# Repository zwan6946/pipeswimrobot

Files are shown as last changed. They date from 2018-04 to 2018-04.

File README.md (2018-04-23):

# pipeswimrobot

#function of the robot:Every day, pipeline leakage causes a large amount of water (or oil, gas,etc.) lost. The old way to detect the pipeline leakage always consume a lot of times and human resources. It is in need to have an new leakage detection	way to offer help. SwimBot is designed for low-cost, constantly-running leakage detection.
#
#Design:

location detecting:
Using the IMU built in the Arduino 101 board, which include 3-axis gyroscope and 3-axis accelerometer, to detect the position.
Writing data as a format of the number, time, microphone, 3-axis gyroscope and 3-axis accelerometer into sd card.
Using outside Matlab function to analyzing the data we load in SD card to get the position of leaking. and also use machine learning to simulate the size of leaking

Microphone 
Maxim MAX4466 is an op-amp specifically designed for a delicate task which can recorded 20-20KHZ electret sounds. This microphone is very suitable for detecting varieties size of leaking. 

M100 Brushless Motor with propeller ($82.00)
This motor is a rugged brushless motor for use in the ocean and in extreme environments. This propeller with M100 motor can generates about 3.2 lb of forward thrust and 2.6 ln of  reverse thrust.

Speed controller 
This controller is based on the BLHeli_S ESC design, providing an speed control and voltage adjustment for Motors.

Outfit
Using 3D printer to print a special outer casing or shell for this swimming robot. The whole device is designed like a bullet so it can reduce the force of water. There is a gap surrounding the chips so it can isolate water from chips

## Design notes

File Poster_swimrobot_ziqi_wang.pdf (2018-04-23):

# Developing swimming in pipe robot

## Student: Ziqi Wang, Electrical Engineering (computer), University of Sydney

Director: Dr. Stevan Dubljevic, Department of Chemical and Material Engineering, University of Alberta

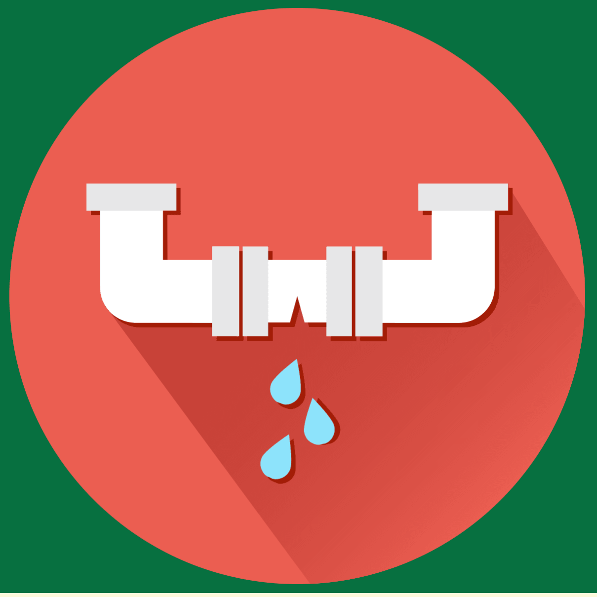
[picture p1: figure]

## Introduction

Every day, pipeline leakage causes a large amount of water (or oil, gas,etc.) lost. The old way to detect the pipeline leakage always consume a lot of times and human resources.
It is in need to have an new leakage detection way to offer help. SwimBot is designed for low-cost, constantly-running leakage detection.

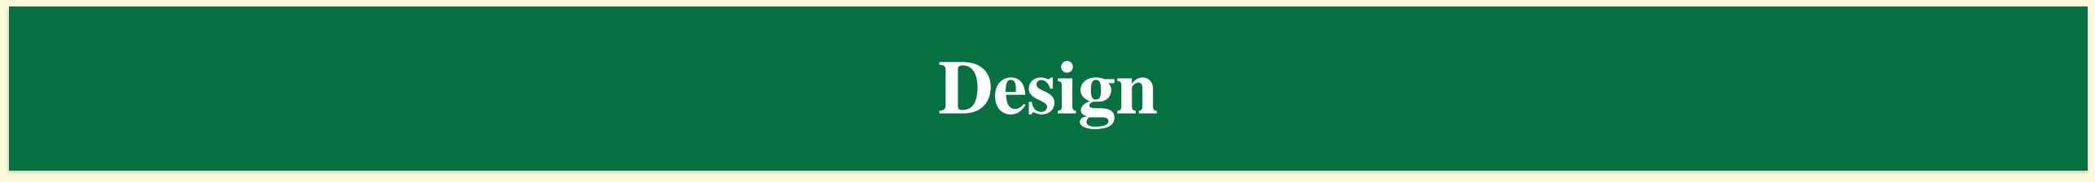
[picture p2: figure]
Design

Hardware
Arduino 101 microcontroller ($30.00)
This board has low power consumption of inter curie module with an IMU and a Bluetooth unit inside. There are 14 output/input pins on this board, which can provide enough interface for this project.

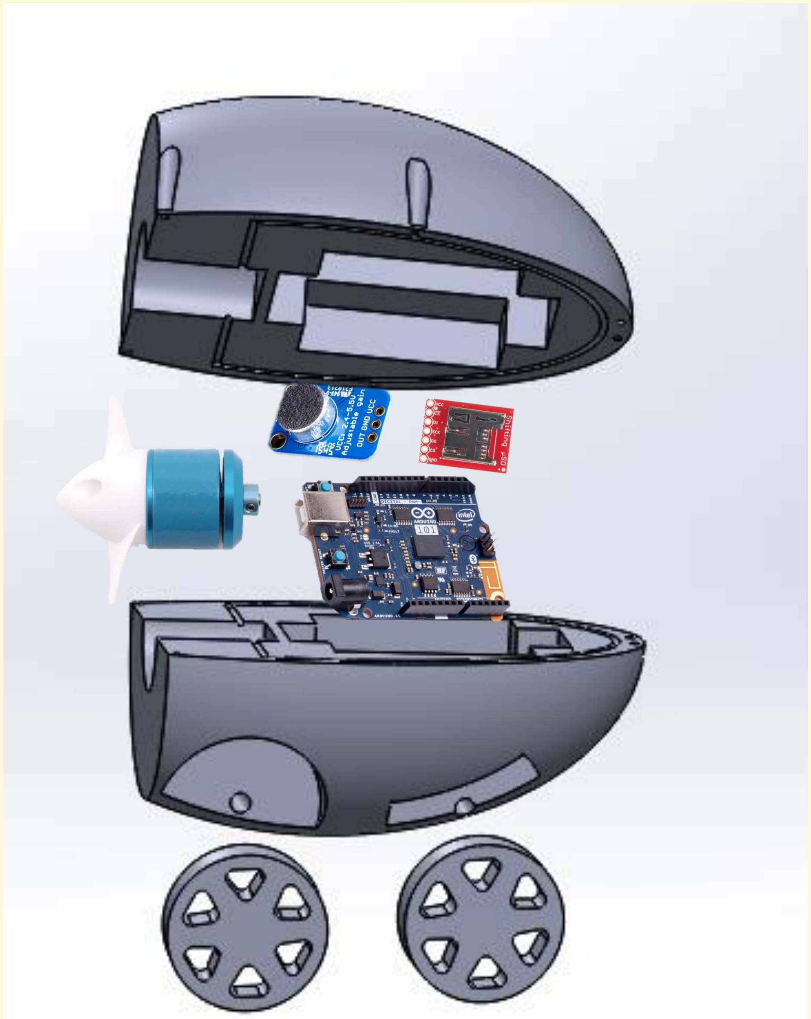
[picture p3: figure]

Microphone ($6.49)
Maxim MAX4466 is an op-amp specifically designed for a delicate task which can recorded 20-20KHZ electret sounds. This microphone is very suitable for detecting varieties size of leaking.

MicroSD Shied ($4.95)
Using MicroSD card to minimize the size of the core part and also use it to load IMU data and Microphone data.

M100 Brushless Motor with propeller ($82.00) This motor is a rugged brushless motor for use in the ocean and in extreme environments. This propeller with M100 motor can generates about 3.2 lb of forward thrust and 2.6 ln of reverse thrust.

Speed controller ($25.00)
This controller is based on the BLHeli_S ESC design, providing an speed control and voltage adjustment for Motors.

Outfit
Using 3D printer to print a special outer casing or shell for this swimming robot. The whole device is designed like a bullet so it can reduce the force of water. There is a gap surrounding the chips so it can isolate water from chips.

Software
IMU
IMU (Inertial measurement unit) is an electronic device that measures and reports a body‘s specific force and angular rate, using a combination of accelerometer and gyroscope.

Big Data Analysis
To detect the leak with sound data, we should find ways to tell apart the difference between normal sound signals and the ones at leak points.
Once we get the raw data of the sound from the microphone, we should first identify the feature vector of the sound. Then, we use machine learning methods to classify leak and non-leak situations.

## Methods

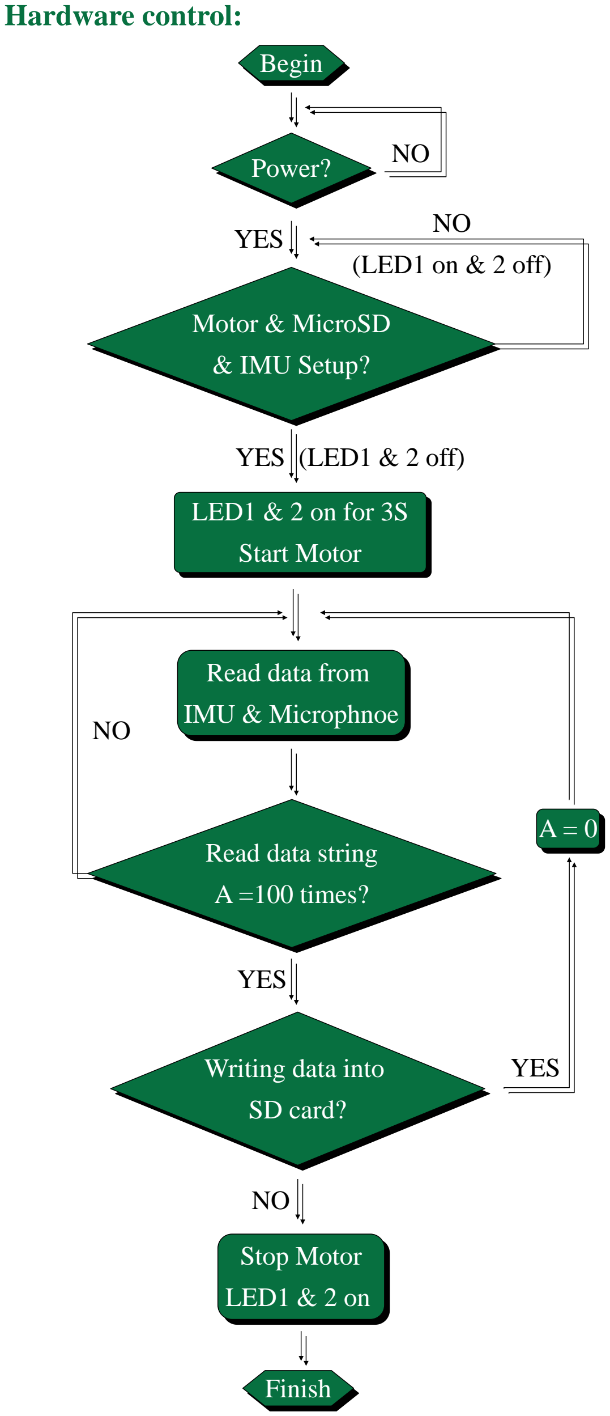
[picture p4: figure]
Hardware control:; Power?; Begin; YES; Motor & MicroSD; & IMU Setup?; (LED1 on & 2 off); YES (LED1 & 2 off); LED1 & 2 on for 3S; Start Motor; Read data string; A =100 times?; Read data from; IMU & Microphnoe NO; Writing data into; SD card?; Stop Motor; LED1 & 2 on; Finish

Position Detection

Using the IMU built in the Arduino 101 board, which include 3-axis gyroscope and 3-axis accelerometer, to detect the position.
Writing data as a format of the number, time, microphone, 3-axis gyroscope and 3-axis accelerometer into sd card. Using outside Matlab function to analyzing the data we load in SD card to get the position of leaking. and also use machine learning to simulate the size of leaking

3D model of swimrobot

## Conclusions

Power consumption

The motor consumes a lot of energies, a 600mAh battery can only support for 30 minis as the motor is running at a maximum speed.

Motor

This type of motor is perfect for small devices which require going deep into the water. This motor also provides adjustable forward and backward thrust. This force can be used to break the clogging pipes.

Data processing

There is some conflict between IO interfaces, which causes the unstable of data collection. The time used in writing data into SD card when getting 100 groups of data, may cause lost one or two groups of data. However, the influence to the position detection can be eliminated.

## Further Study

- Try to using FPGA to building an stable version of swimming robot, Which will reduce the conflict between IO ports.
- Using machine learning to calculate the position of the swimming robot, like to calculate the rest state of the ball.
- Adding some universal wheels into the outfit of the swimrobot in order to make it turn more flexibly in the pipe line.
- More functions can be added into the swimrobot, such as, a press sensor in front can detect the clogging point of the pipe.
- Changing the design of swimrobot, make it more convenient to insert or pull out sd card.

## Team Member

Azzam Hazim, University of Alberta Junyao Xie, University of Alberta Kimmy , University of Alberta

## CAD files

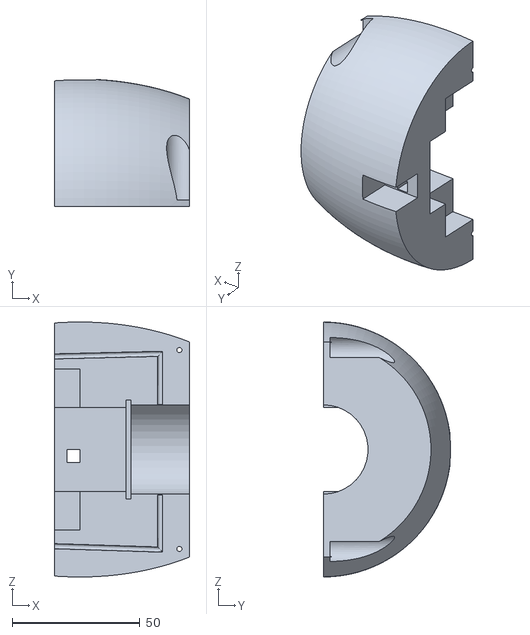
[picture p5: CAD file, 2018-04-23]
SWIM7_part1a.STL
53.0 x 49.8 x 100.0

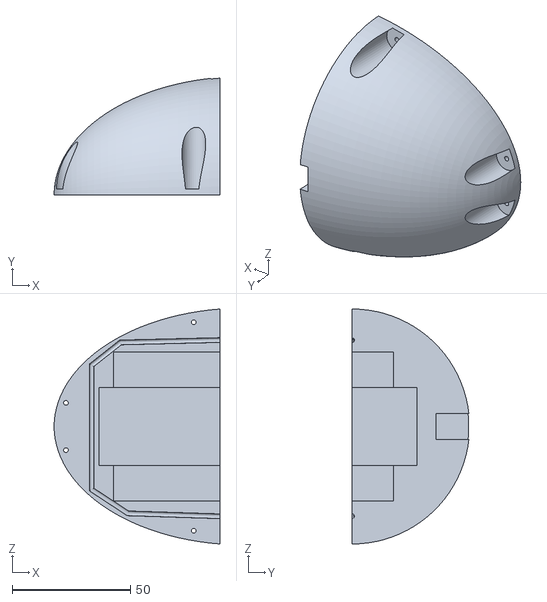
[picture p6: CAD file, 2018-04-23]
SWIM7_part1b.STL
70.0 x 49.3 x 99.2

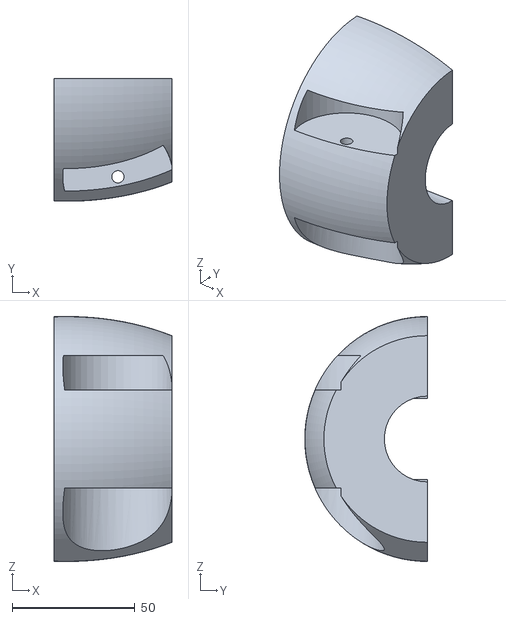
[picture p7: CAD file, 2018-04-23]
SWIM7_part2a.STL
48.0 x 50.0 x 100.0

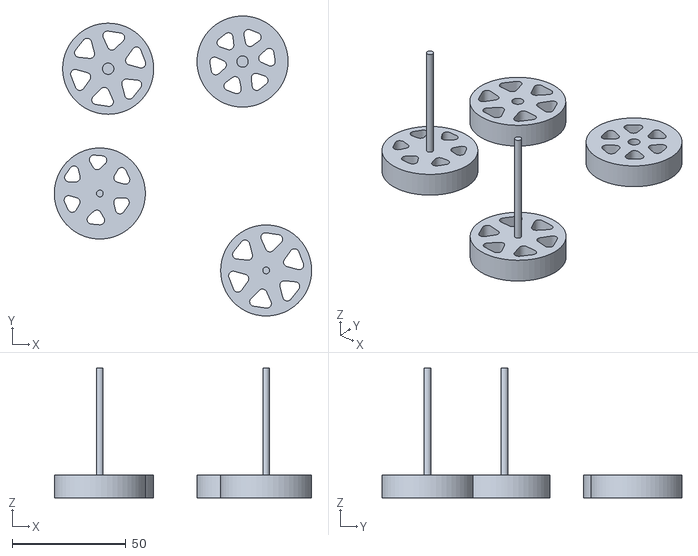
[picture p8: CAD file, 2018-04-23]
SWIM7_part4.STL
113.0 x 131.7 x 57.0

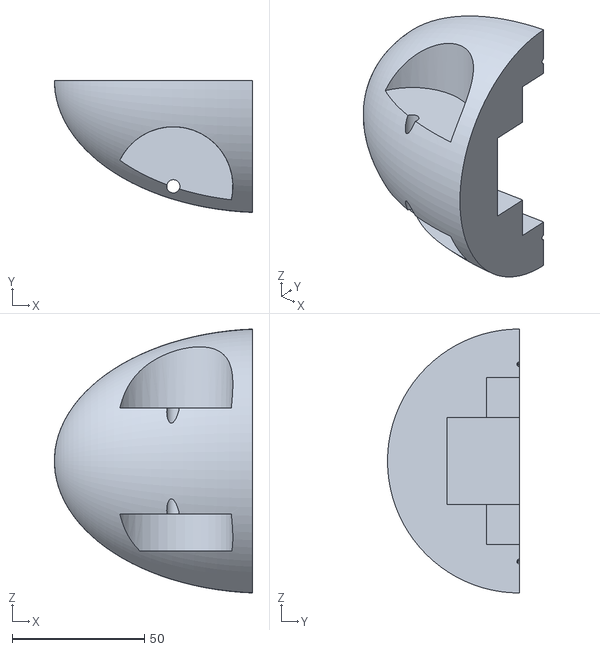
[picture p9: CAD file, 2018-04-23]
SWIM7_part2b.STL
75.0 x 49.9 x 99.8

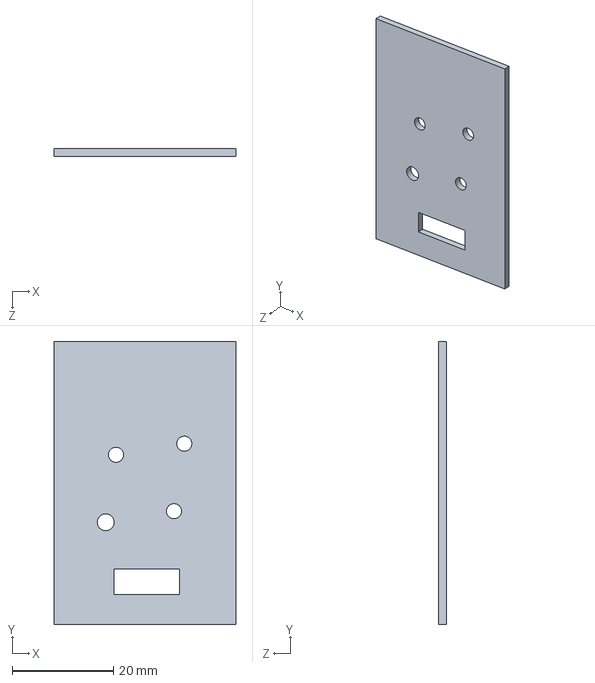
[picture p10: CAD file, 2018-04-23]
SWIM7_part3.SLDPRT
36.0 x 56.0 x 1.50 mm

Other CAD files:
SWIM7_part3.STL
